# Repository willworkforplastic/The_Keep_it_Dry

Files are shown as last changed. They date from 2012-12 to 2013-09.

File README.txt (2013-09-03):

THE KEEP IT DRY

Keeping your precious filament dry since yesterday!

These are the CAD and production files for a small passive dry box to keep 4 Diamond age 1Kg plastic 
spools dry while your tantillus 3D printer is not running. Probably will work for other spool types but
none tested at the time of writing this.

Refer to Keep it Dry.pdf for more detail and assembly notes.

Cheers
Will Work for Plastic 
(and Paintballs)

"Life looks better when you waste the day away" - Everclear

Now for the borring rev history:

1/12/2012:
Intial Release

3/09/2013:
Added in Door bracing to prevent door warpage from occuring resulting in loss of sealing around foam seal.

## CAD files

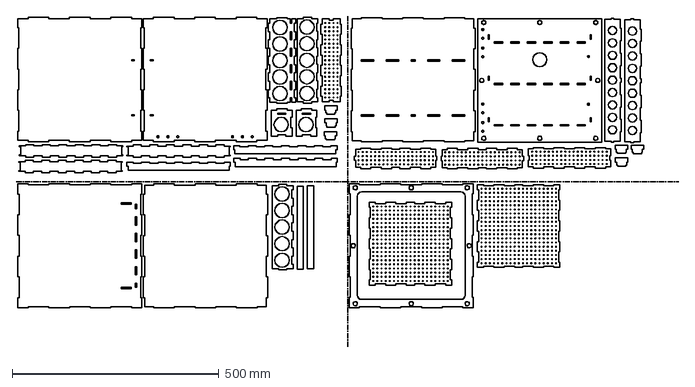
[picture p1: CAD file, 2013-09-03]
Laser Cutting Files/All Panels Keep it Dry VLS6_60.DXF
1600.0 x 799.3 mm

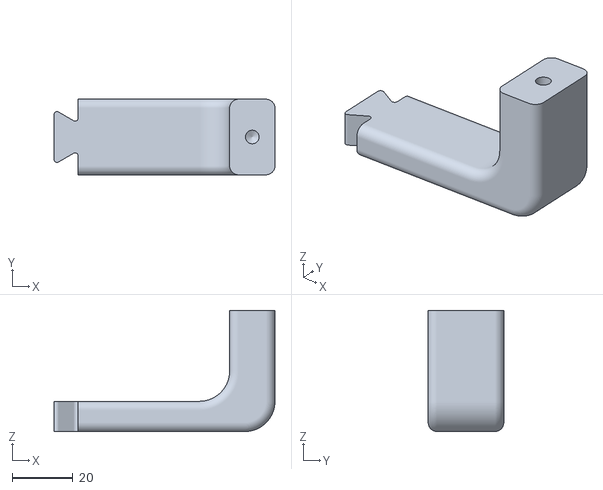
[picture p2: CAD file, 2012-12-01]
STLs for Printing/Handle B.STL
73.0 x 25.0 x 40.0

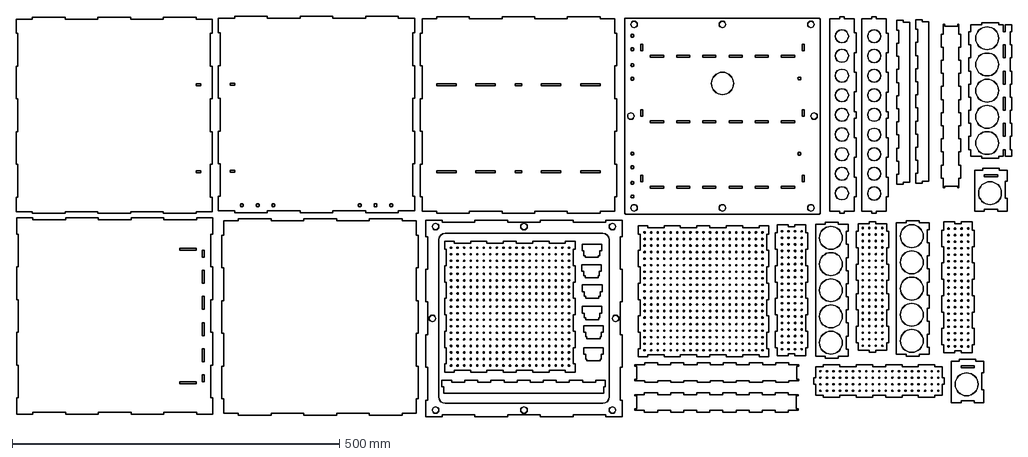
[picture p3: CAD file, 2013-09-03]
Laser Cutting Files/All panels Keep it Dry.DXF
1521.1 x 611.1 mm

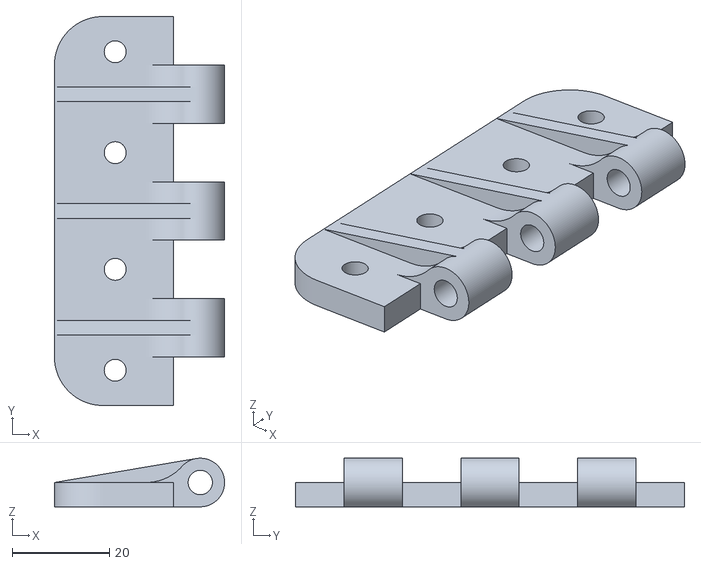
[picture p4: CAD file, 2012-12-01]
STLs for Printing/Hinge B.STL
35.0 x 80.0 x 10.00

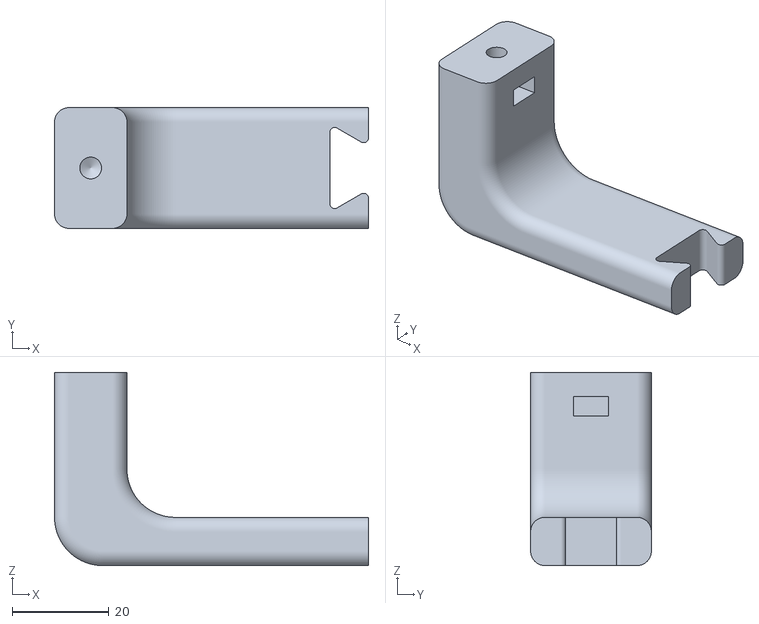
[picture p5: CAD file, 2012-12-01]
STLs for Printing/Handle A.STL
65.0 x 25.0 x 40.0

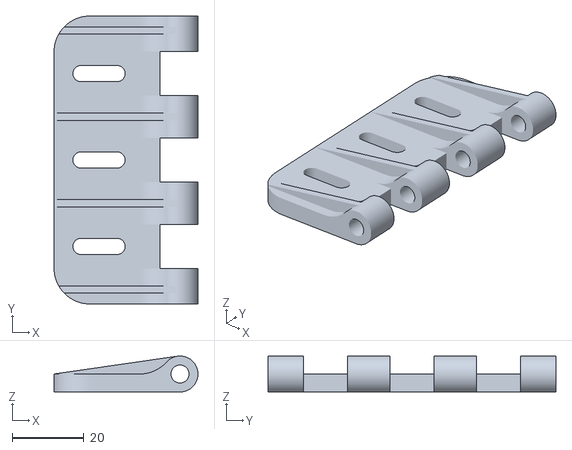
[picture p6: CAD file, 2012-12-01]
STLs for Printing/Hinge A.STL
40.0 x 80.0 x 10.00

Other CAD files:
Keep it Dry.x_t

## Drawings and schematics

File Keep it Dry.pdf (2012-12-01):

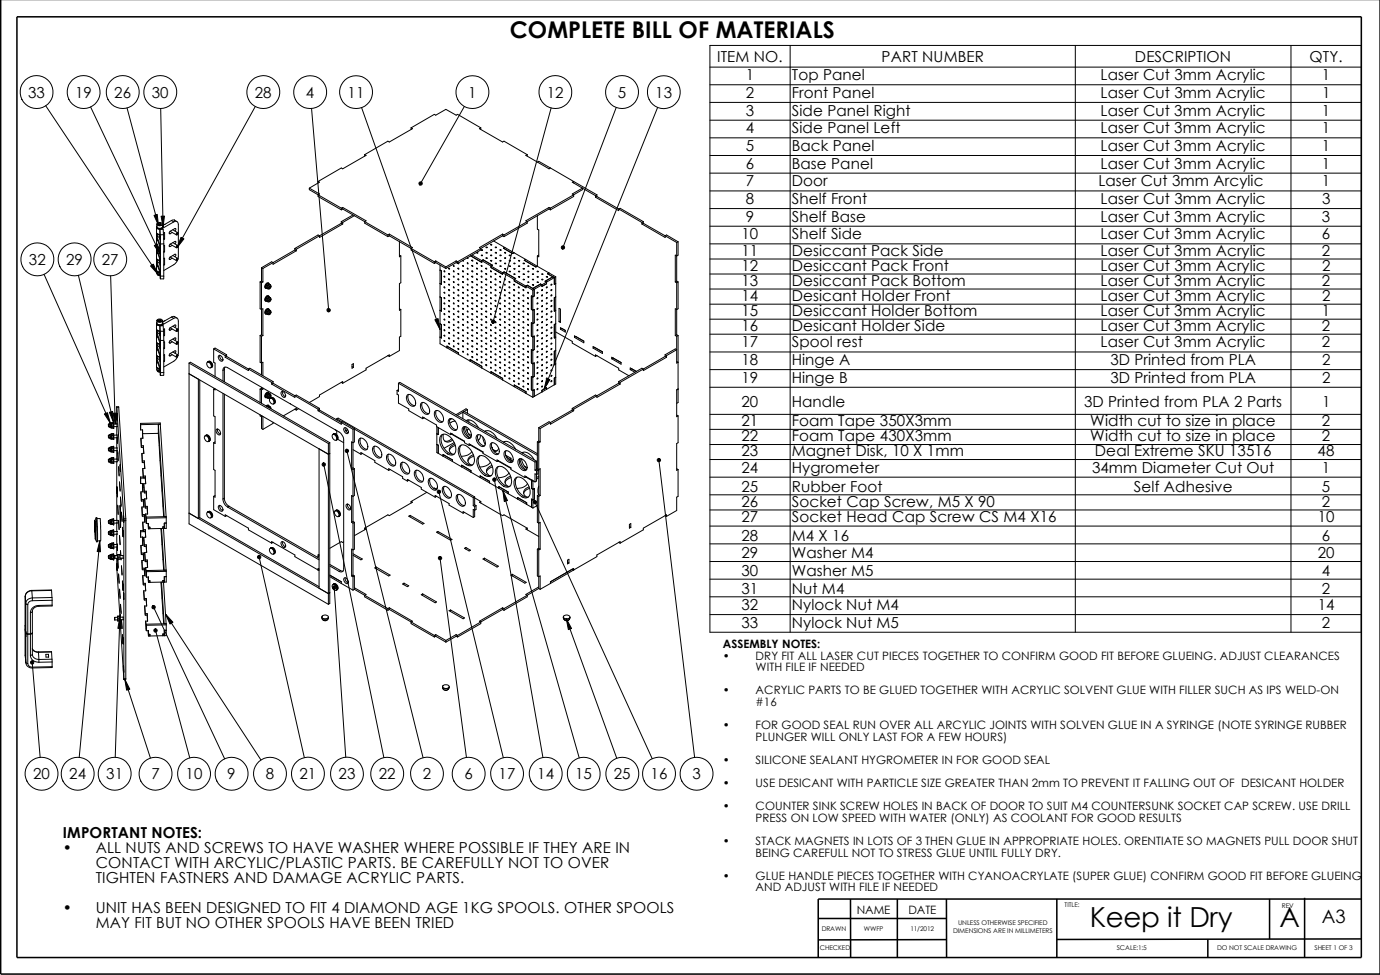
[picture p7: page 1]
MAY FIT BUT NO OTHER SPOOLS HAVE BEEN TRIED; WWFP; Keep it Dry

COMPLETE BILL OF MATERIALS

ITEM NO. | PART NUMBER | DESCRIPTION | QTY.
1 | Top Panel | Laser Cut 3mm Acrylic | 1
2 | Front Panel | Laser Cut 3mm Acrylic | 1
3 | Side Panel Right | Laser Cut 3mm Acrylic | 1
4 | Side Panel Left | Laser Cut 3mm Acrylic | 1
5 | Back Panel | Laser Cut 3mm Acrylic | 1
6 | Base Panel | Laser Cut 3mm Acrylic | 1
7 | Door | Laser Cut 3mm Arcylic | 1
8 | Shelf Front | Laser Cut 3mm Acrylic | 3
9 | Shelf Base | Laser Cut 3mm Acrylic | 3
10 | Shelf Side | Laser Cut 3mm Acrylic | 6
11 | Desiccant Pack Side | Laser Cut 3mm Acrylic | 2
12 | Desiccant Pack Front | Laser Cut 3mm Acrylic | 2
13 | Desiccant Pack Bottom | Laser Cut 3mm Acrylic | 2
14 | Desicant Holder Front | Laser Cut 3mm Acrylic | 2
15 | Desiccant Holder Bottom | Laser Cut 3mm Acrylic | 1
16 | Desicant Holder Side | Laser Cut 3mm Acrylic | 2
17 | Spool rest | Laser Cut 3mm Acrylic | 2
18 | Hinge A | 3D Printed from PLA | 2
19 | Hinge B | 3D Printed from PLA | 2
20 | Handle | 3D Printed from PLA 2 Parts | 1
21 | Foam Tape 350X3mm | Width cut to size in place | 2
22 | Foam Tape 430X3mm | Width cut to size in place | 2
23 | Magnet Disk, 10 X 1mm | Deal Extreme SKU 13516 | 48
24 | Hygrometer | 34mm Diameter Cut Out | 1
25 | Rubber Foot | Self Adhesive | 5
26 | Socket Cap Screw, M5 X 90 | | 2
27 | Socket Head Cap Screw CS M4 X16 | | 10
28 | M4 X 16 | | 6
29 | Washer M4 | | 20
30 | Washer M5 | | 4
31 | Nut M4 | | 2
32 | Nylock Nut M4 | | 14
33 | Nylock Nut M5 | | 2

ASSEMBLY NOTES:
• DRY FIT ALL LASER CUT PIECES TOGETHER TO CONFIRM GOOD FIT BEFORE GLUEING. ADJUST CLEARANCES
WITH FILE IF NEEDED

• ACRYLIC PARTS TO BE GLUED TOGETHER WITH ACRYLIC SOLVENT GLUE WITH FILLER SUCH AS IPS WELD-ON

• FOR GOOD SEAL RUN OVER ALL ARCYLIC JOINTS WITH SOLVEN GLUE IN A SYRINGE (NOTE SYRINGE RUBBER
PLUNGER WILL ONLY LAST FOR A FEW HOURS)

• SILICONE SEALANT HYGROMETER IN FOR GOOD SEAL

• USE DESICANT WITH PARTICLE SIZE GREATER THAN 2mm TO PREVENT IT FALLING OUT OF DESICANT HOLDER

• COUNTER SINK SCREW HOLES IN BACK OF DOOR TO SUIT M4 COUNTERSUNK SOCKET CAP SCREW. USE DRILL
PRESS ON LOW SPEED WITH WATER (ONLY) AS COOLANT FOR GOOD RESULTS

IMPORTANT NOTES:
• ALL NUTS AND SCREWS TO HAVE WASHER WHERE POSSIBLE IF THEY ARE IN
CONTACT WITH ARCYLIC/PLASTIC PARTS. BE CAREFULLY NOT TO OVER
TIGHTEN FASTNERS AND DAMAGE ACRYLIC PARTS.

• STACK MAGNETS IN LOTS OF 3 THEN GLUE IN APPROPRIATE HOLES. ORENTIATE SO MAGNETS PULL DOOR SHUT
BEING CAREFULL NOT TO STRESS GLUE UNTIL FULLY DRY.

• GLUE HANDLE PIECES TOGETHER WITH CYANOACRYLATE (SUPER GLUE) CONFIRM GOOD FIT BEFORE GLUEING
AND ADJUST WITH FILE IF NEEDED

• UNIT HAS BEEN DESIGNED TO FIT 4 DIAMOND AGE 1KG SPOOLS. OTHER SPOOLS

NAME | DATE | UNLESS OTHERWISE SPECIFIED DIMENSIONS ARE IN MILLIMETERS | TITLE: | REV A

DRAWN | | 11/2012

CHECKED | | | | SCALE:1:5 | DO NOT SCALE DRAWING | SHEET 1 OF 3

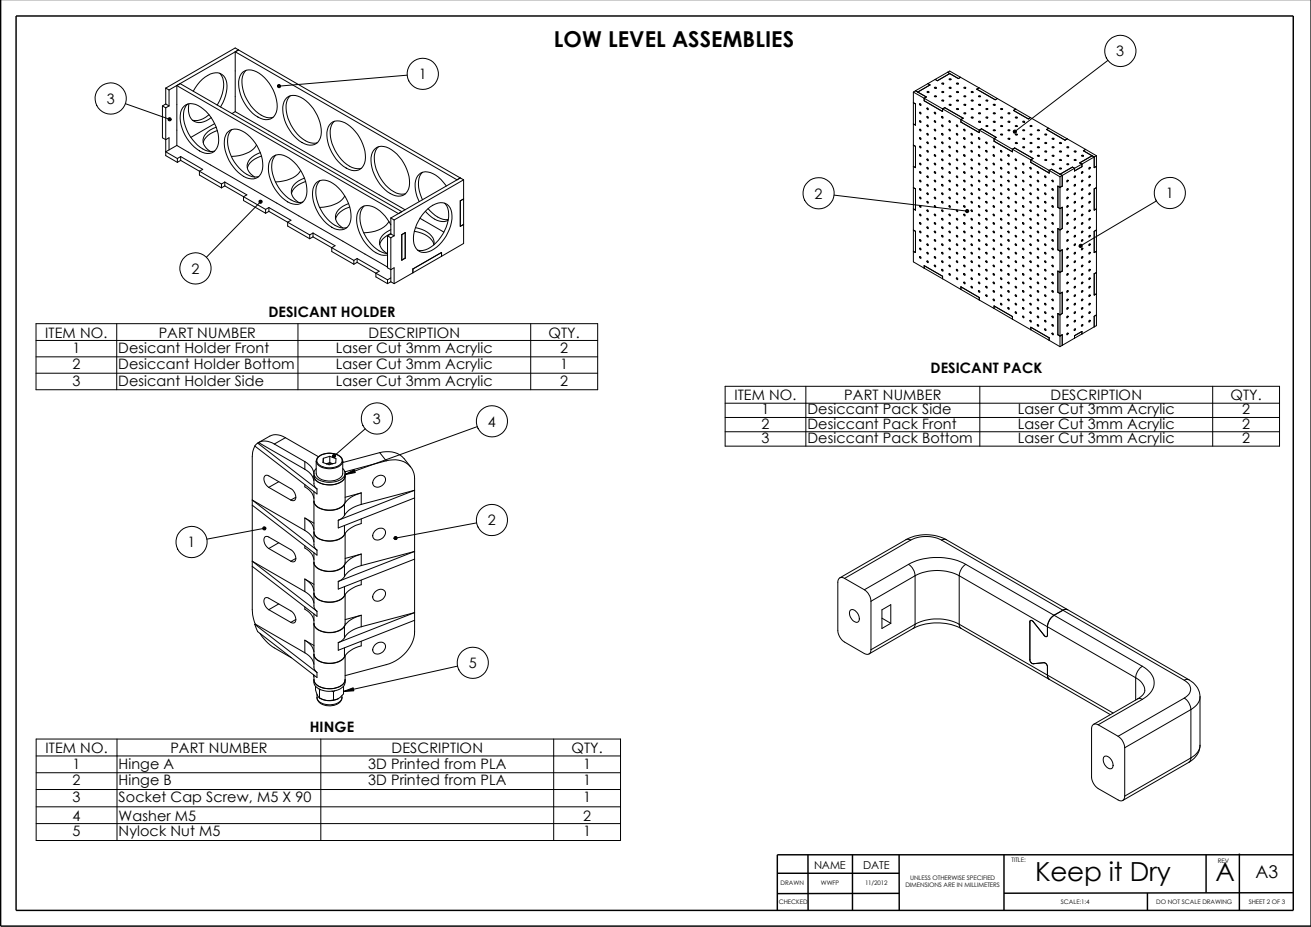
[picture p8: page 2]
DESICANT HOLDER; HINGE; DESICANT PACK

LOW LEVEL ASSEMBLIES

ITEM NO. | PART NUMBER | DESCRIPTION | QTY.
1 | Desicant Holder Front | Laser Cut 3mm Acrylic | 2
2 | Desiccant Holder Bottom | Laser Cut 3mm Acrylic | 1
3 | Desicant Holder Side | Laser Cut 3mm Acrylic | 2

1 | Desiccant Pack Side | Laser Cut 3mm Acrylic | 2
2 | Desiccant Pack Front | Laser Cut 3mm Acrylic | 2
3 | Desiccant Pack Bottom | Laser Cut 3mm Acrylic | 2

1 | Hinge A | 3D Printed from PLA | 1
2 | Hinge B | 3D Printed from PLA | 1
3 | Socket Cap Screw, M5 X 90 | | 1
4 | Washer M5 | | 2
5 | Nylock Nut M5 | | 1

WWFP | 11/2012 | DIMENSIONS ARE IN MILLIMETERS UNLESS OTHERWISE SPECIFIED | Keep it Dry | A | A3

DRAWN

SCALE:1:4 | | SHEET 2 OF 3

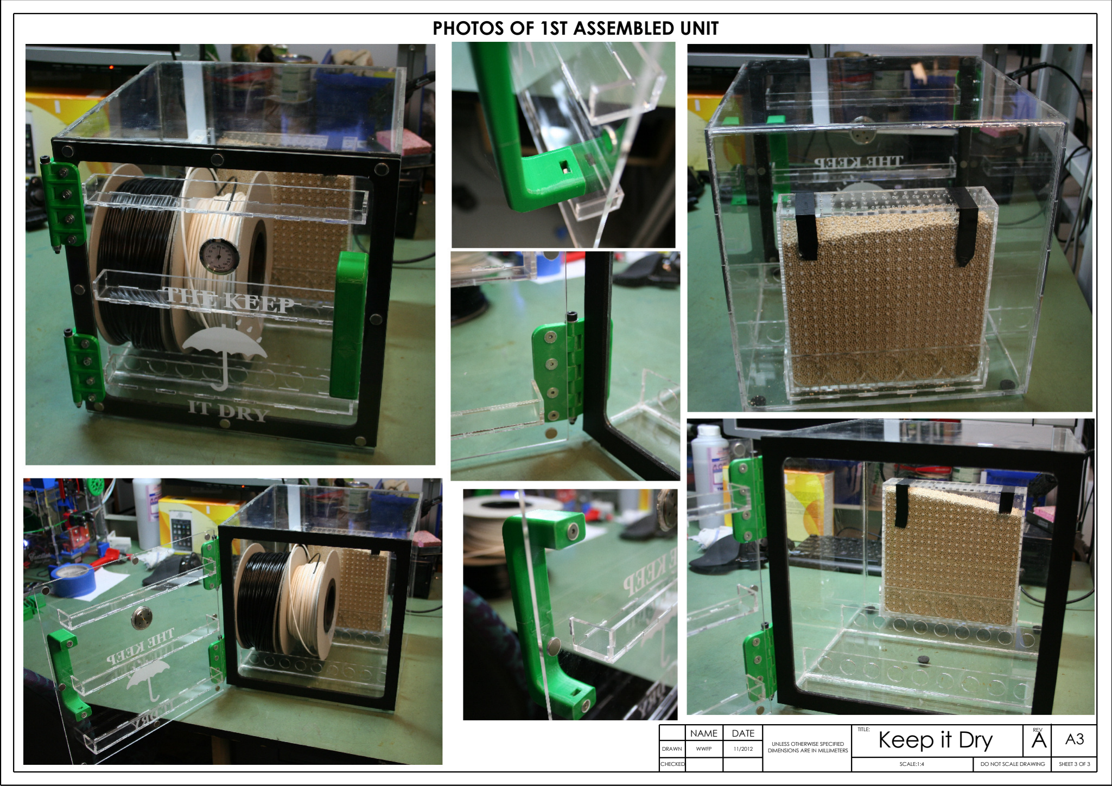
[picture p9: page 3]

| WWFP | 11/2012 | DIMENSIONS ARE IN MILLIMETERS UNLESS OTHERWISE SPECIFIED | Keep it Dry | A | A3
SCALE:1:4 | | SHEET 3 OF 3

DRAWN

### PHOTOS OF 1ST ASSEMBLED UNIT

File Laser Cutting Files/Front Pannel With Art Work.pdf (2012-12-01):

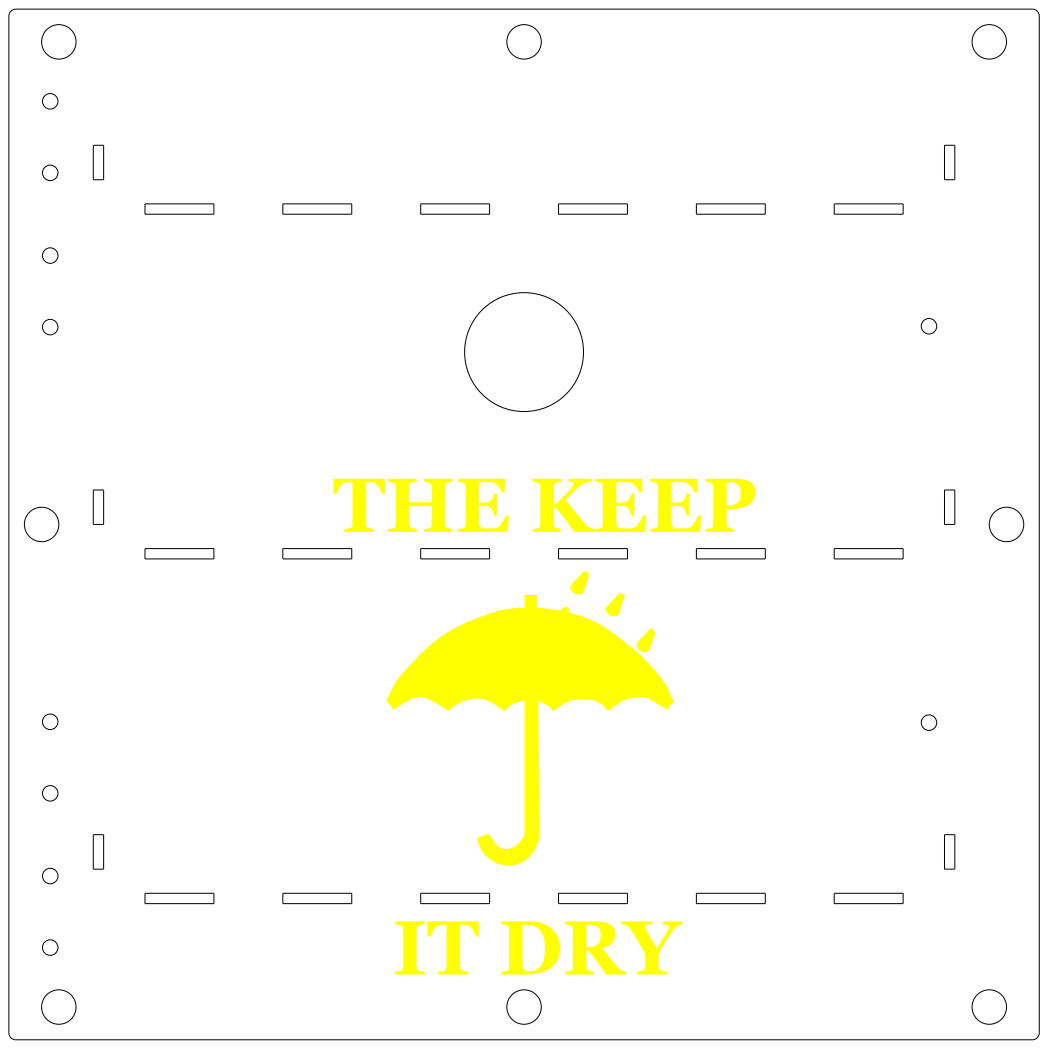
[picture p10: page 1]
THE KEEP; IT DRY

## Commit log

2012-12-01 Intial Release
    [All Panels Keep it Dry VLS6_60.DXF, All panels Keep it Dry.DXF, Handle A.STL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]
2013-09-03 REV B Added more Door Bracing
    Added Door brace to prevent Door warpage resulting in loss of seal
    [All Panels Keep it Dry VLS6_60.DXF, All panels Keep it Dry.DXF, Keep it Dry.x_t]
